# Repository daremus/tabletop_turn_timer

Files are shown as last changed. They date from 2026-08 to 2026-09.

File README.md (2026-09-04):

This is a single duration turn timer for tabletop games. It's like an hourglass without the slow reset.

Attribution:
* Code: 99% Gemini.
* Everything else: 99% me.

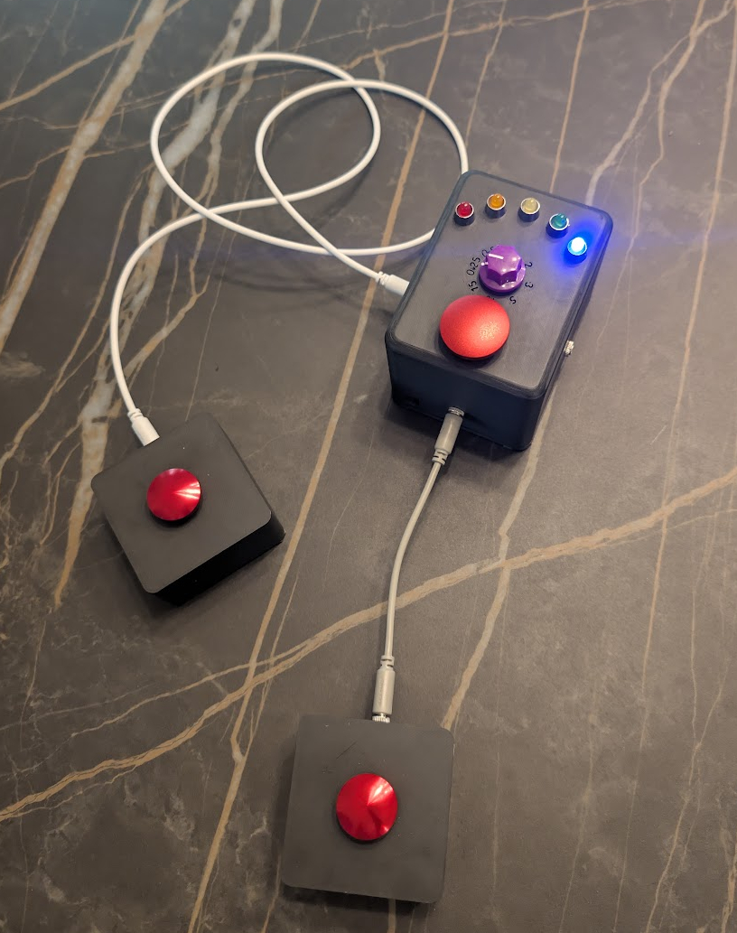
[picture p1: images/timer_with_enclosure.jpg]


## Basic Usage

Everyone has the same time for each turn. The timer resets to that time after every turn.

1. Use the knob to Select a turn duration (t).
1. Turn on timer
1. Press a button: starts a timer
1. Player presses the button when their turn is complete, timer starts the next player's turn.
1. If the timer ends before a button is pressed, the device will beep and then sleep.
1. Double press the button to put the timer to sleep.
1. If the timer is sleeping, press the button to start the next turn
1. LEDs indicate the remaining duration in t/6 chunks. LED 1 lights for the first 1/6 of a turn, LED 2 lights for the second 1/6, and so on. LED 5 lights for the fifth chunk and then flashes for the final chunk.

## Details
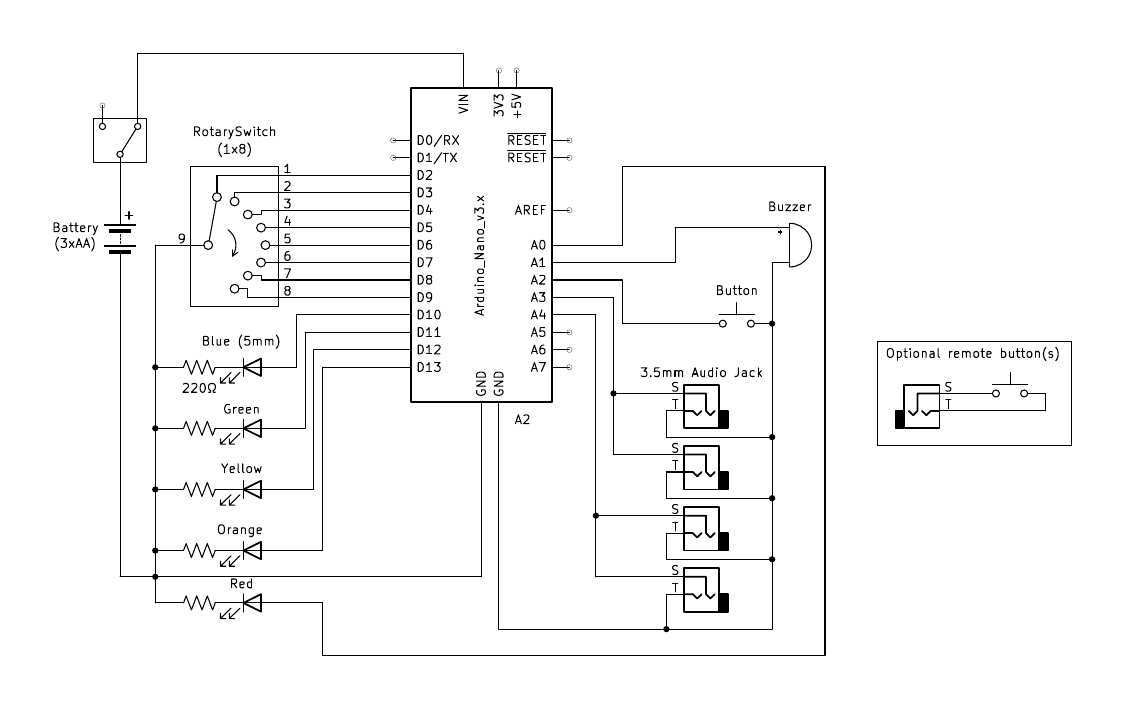
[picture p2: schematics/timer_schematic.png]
* Wiring schematic: 
* TS jacks are used to hook up external buttons and are not really needed.
  
## Components
* Panel mount mushroom head buttons: [22mm](https://www.amazon.com/dp/B0CKV6B81P), [16mm (1)](https://www.sparkfun.com/16mm-metal-push-button-switch-mushroom-head-red.html), [16mm (2)](https://www.amazon.com/dp/B0FM3VK8YW)
* [Arduino Nano clone](https://www.amazon.com/dp/B0F6Y7GS4Q) / [Arduino Nano Every](https://www.sparkfun.com/arduino-nano-every.html)
* [3.5mm mono jacks](https://www.amazon.com/dp/B0CF9DQYQ6)
* [mini speaker](https://www.amazon.com/dp/B0D7SC3ZFG)/[Buzzer](https://www.amazon.com/dp/B07VK1GJ9X)
* [Battery holder](https://www.sparkfun.com/battery-holder-3xaa-with-cover-and-switch-bare-wire.html) - switch removed and replaced with something like [this one](https://www.sparkfun.com/mini-power-switch-spdt.html) glued to the enclosure.
* [LED holders](https://www.sparkfun.com/led-holder-5mm-chrome-finish.html)
* M2 x 4mm [heat set threaded inserts](https://www.amazon.com/dp/B0FD7DQS8Y)
* M2 x 5mm screws
* [Solderable breadboard](https://www.amazon.com/dp/B0B27XB69M)

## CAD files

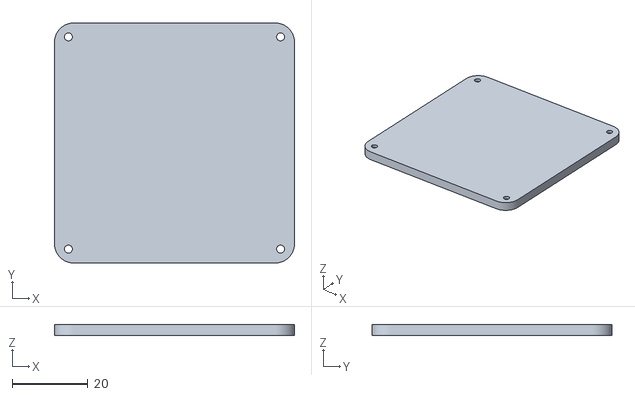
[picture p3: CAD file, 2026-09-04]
enclosures/remote button enclosure bottom.stl
63.5 x 63.5 x 3.00

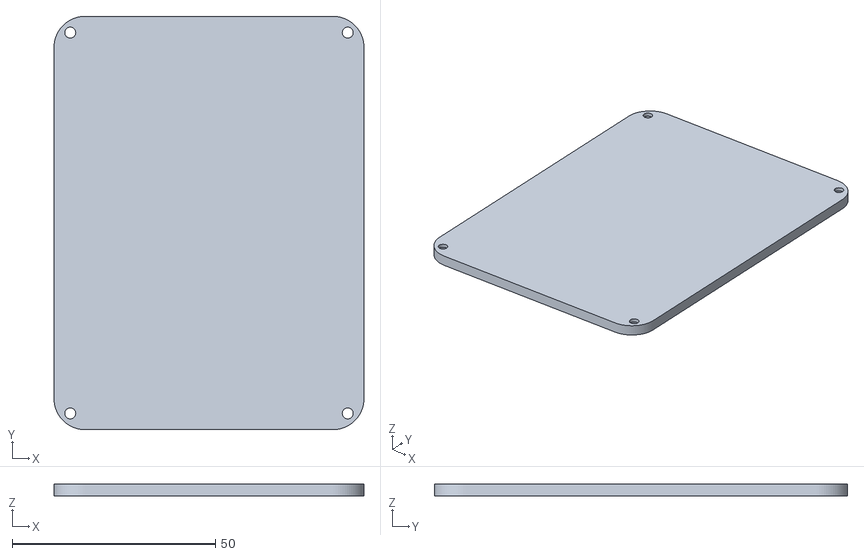
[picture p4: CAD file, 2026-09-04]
enclosures/enclosure bottom.stl
76.2 x 101.6 x 3.00

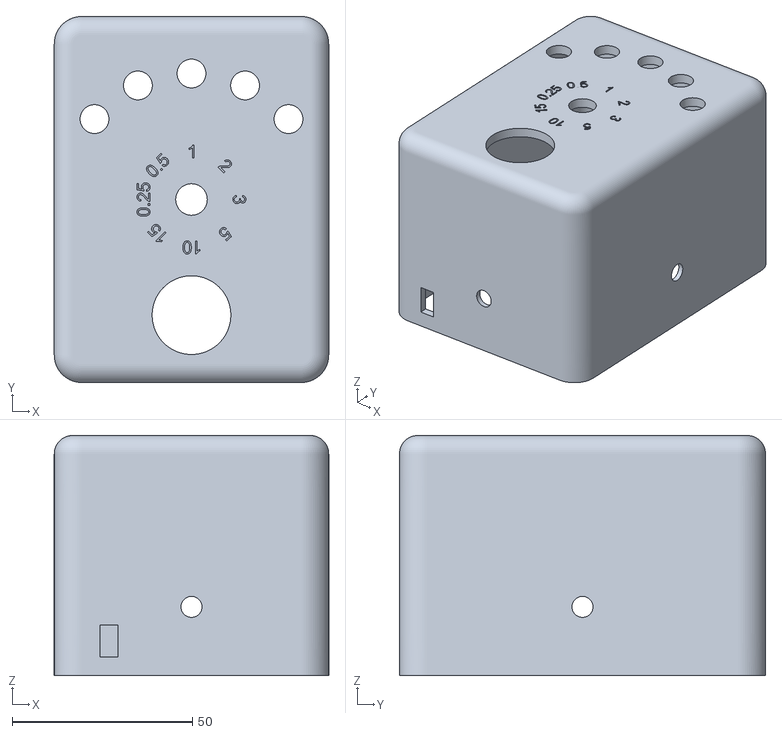
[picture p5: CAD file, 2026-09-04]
enclosures/enclosure.stl
76.2 x 101.6 x 66.6

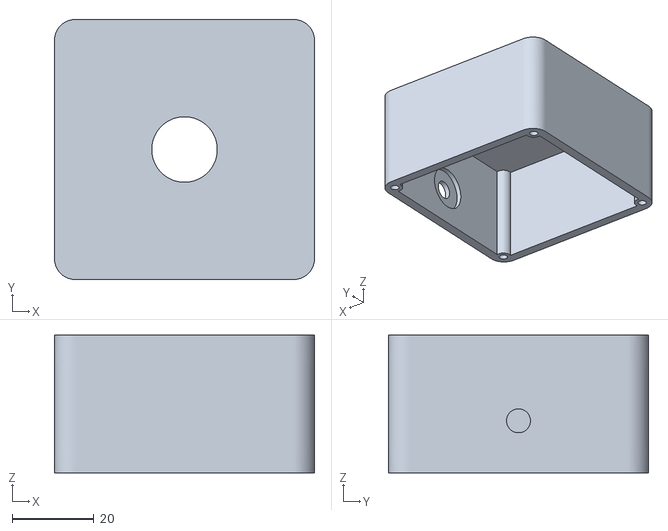
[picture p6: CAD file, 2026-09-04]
enclosures/remote button enclosure.stl
63.5 x 63.5 x 33.6

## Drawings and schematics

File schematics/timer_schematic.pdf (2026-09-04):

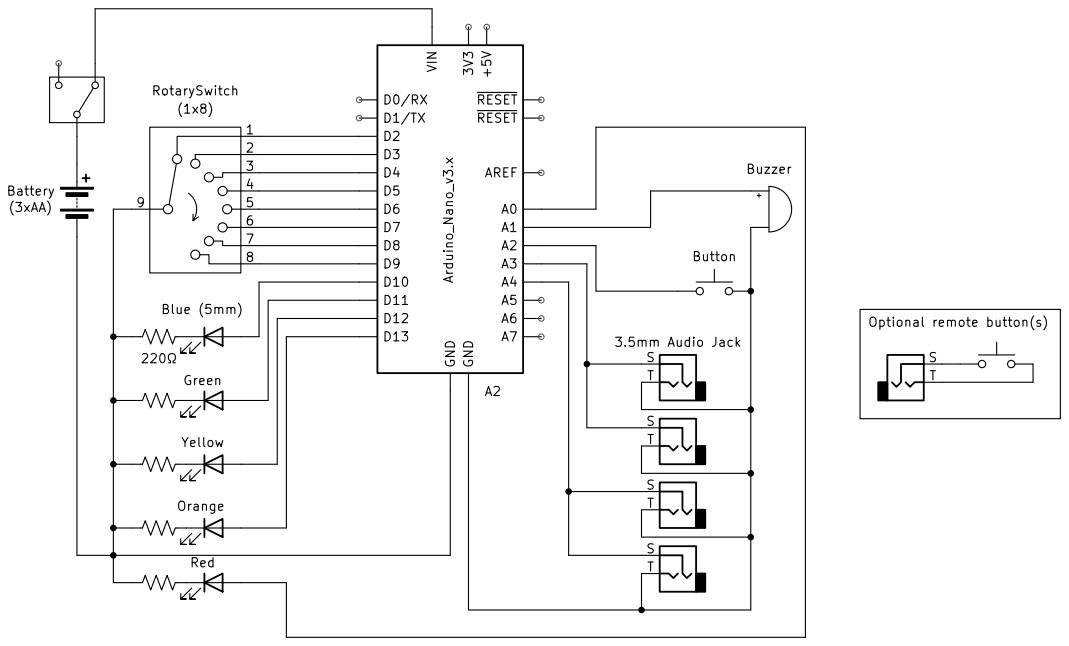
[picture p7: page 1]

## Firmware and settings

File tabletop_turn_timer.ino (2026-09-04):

/*
  Tabletop Game Timer
  
  Turn-based countdown timer configured with an 8-position rotary switch,
  remote player jacks, main button, passive piezo sounder (B0D7SC3ZFG),
  and a 5-LED display.
*/

// ==========================================
// PIN DEFINITIONS
// ==========================================
const uint8_t rotaryPins[] = {2, 3, 4, 5, 6, 7, 8, 9};
const uint8_t numRotaryPositions = sizeof(rotaryPins) / sizeof(rotaryPins[0]);

const uint8_t jackPins[] = {A3, A4};
const uint8_t numJacks = sizeof(jackPins) / sizeof(jackPins[0]);

const uint8_t mainButtonPin = A2;
const uint8_t buzzerPin = A1; // Passive Piezo Sounder (B0D7SC3ZFG)

// LED Pins: LED1 = D10 (PWM), LED2 = D11 (PWM), LED3 = D12, LED4 = D13, LED5 = A0
const uint8_t ledPins[] = {10, 11, 12, 13, A0};
const uint8_t numLeds = sizeof(ledPins) / sizeof(ledPins[0]);

// ==========================================
// CONFIGURATION & PRESETS
// ==========================================
// Durations for Positions 1 to 8: 1m, 2m, 3m, 5m, 10m, 15m, 15s, 30s
const uint32_t durationPresetsMs[] = {
  60000UL, 120000UL, 180000UL, 300000UL,
  600000UL, 900000UL, 15000UL, 30000UL
};

// Input debouncing & multi-tap detection
const uint32_t debounceDelayMs = 35;
const uint32_t doubleTapWindowMs = 380;

// Alarm sequence: 3 beeps driven at the piezo's resonant frequency (3.1 kHz)
const uint8_t maxAlarmBeeps = 3;
const uint32_t alarmBeepDurationMs = 200;
const uint16_t alarmResonantFreqHz = 3100;

// Turn-start sweep: 2 runs (LED1 -> LED5 -> LED1, 9 steps over ~0.5s)
const uint8_t startSweepPattern[] = {0, 1, 2, 3, 4, 3, 2, 1, 0};
const uint8_t numSweepSteps = sizeof(startSweepPattern);
const uint32_t sweepStepIntervalMs = 55; // 9 * 55ms = 495ms

// Turn-start tone: Warm ~450 Hz "boooop" (1111 µs half-period) over 120 ms
const uint32_t startToneDurationMs = 120;
const uint32_t toneToggleHalfPeriodUs = 1111;

// Sleep animation (center-out sweep + hardware PWM breathing)
const uint32_t sleepOutwardStepMs = 140;
const uint32_t pulseUpdateIntervalMs = 20;

// ==========================================
// STATE MACHINE & RUNTIME VARIABLES
// ==========================================
enum TimerState {
  STATE_IDLE,
  STATE_RUNNING,
  STATE_ALARM,
  STATE_START_ALERT,
  STATE_SLEEP_SWEEP,
  STATE_SLEEPING
};

TimerState currentState = STATE_IDLE;

// Timing counters
uint32_t totalDurationMs = 60000UL;
uint32_t timeRemainingMs = 60000UL;
uint32_t lastTimerUpdateMs = 0;

// Alarm tracking
uint32_t lastAlarmToggleMs = 0;
uint8_t alarmBeepCount = 0;
bool alarmBeepActive = false;

// Turn-start animation tracking
uint32_t startAlertBeginMs = 0;
uint32_t lastSweepStepMs = 0;
uint32_t lastToneToggleUs = 0;
uint8_t currentSweepIndex = 0;
bool tonePinState = false;

// Sleep sequence tracking
uint32_t lastSleepSweepMs = 0;
uint32_t lastPulseUpdateMs = 0;
uint8_t sleepSweepStep = 0;
int16_t pulseBrightness = 0;
int8_t pulseDirection = 4;

// Button debounce tracking
bool lastRawMainBtn = HIGH;
bool stableMainBtn = HIGH;
uint32_t lastMainDebounceMs = 0;

bool lastRawJack[numJacks] = {HIGH, HIGH};
bool stableJack[numJacks] = {HIGH, HIGH};
uint32_t lastJackDebounceMs[numJacks] = {0, 0};

uint8_t clickCount = 0;
uint32_t lastClickTimeMs = 0;

// ==========================================
// FUNCTION DECLARATIONS
// ==========================================
void handleInputs();
void updateTimer();
void updateStartAlert();
void updateSleepAnimation();
void updateRunningLeds();
void updateAlarm();
void setAllLeds(uint8_t state);
void resetPwmPins();
void silenceBuzzer();
uint32_t readSelectedDuration();
void triggerTurnStart();
void triggerSleepSequence();

// ==========================================
// SETUP & MAIN LOOP
// ==========================================
void setup() {
  for (uint8_t i = 0; i < numRotaryPositions; i++) {
    pinMode(rotaryPins[i], INPUT_PULLUP);
  }

  for (uint8_t i = 0; i < numJacks; i++) {
    pinMode(jackPins[i], INPUT_PULLUP);
  }

  pinMode(mainButtonPin, INPUT_PULLUP);
  pinMode(buzzerPin, OUTPUT);
  silenceBuzzer();

  for (uint8_t i = 0; i < numLeds; i++) {
    pinMode(ledPins[i], OUTPUT);
    digitalWrite(ledPins[i], LOW);
  }

  totalDurationMs = readSelectedDuration();
  timeRemainingMs = totalDurationMs;
}

void loop() {
  handleInputs();
  updateTimer();
  updateStartAlert();
  updateSleepAnimation();
  updateRunningLeds();
  updateAlarm();
}

// ==========================================
// HELPER UTILITIES
// ==========================================
void setAllLeds(uint8_t state) {
  for (uint8_t i = 0; i < numLeds; i++) {
    digitalWrite(ledPins[i], state);
  }
}

void resetPwmPins() {
  analogWrite(ledPins[0], 0);
  analogWrite(ledPins[1], 0);
}

void silenceBuzzer() {
  noTone(buzzerPin);
  digitalWrite(buzzerPin, LOW);
  tonePinState = false;
}

uint32_t readSelectedDuration() {
  for (uint8_t i = 0; i < numRotaryPositions; i++) {
    if (digitalRead(rotaryPins[i]) == LOW) {
      return durationPresetsMs[i];
    }
  }
  return durationPresetsMs[0];
}

// ==========================================
// STATE TRIGGERS
// ==========================================
void triggerTurnStart() {
  startAlertBeginMs = millis();
  lastSweepStepMs = startAlertBeginMs;
  lastToneToggleUs = micros();
  currentSweepIndex = 0;

  resetPwmPins();
  setAllLeds(LOW);
  digitalWrite(ledPins[startSweepPattern[0]], HIGH);

  currentState = STATE_START_ALERT;
}

void triggerSleepSequence() {
  silenceBuzzer();
  resetPwmPins();
  setAllLeds(LOW);

  sleepSweepStep = 0;
  lastSleepSweepMs = millis();
  currentState = STATE_SLEEP_SWEEP;
}

// ==========================================
// INPUT HANDLING & DEBOUNCE
// ==========================================
void handleInputs() {
  const uint32_t now = millis();
  bool pressDetected = false;

  // 1. Debounce Main Pushbutton
  bool rawMain = digitalRead(mainButtonPin);
  if (rawMain != lastRawMainBtn) {
    lastMainDebounceMs = now;
  }
  lastRawMainBtn = rawMain;

  if ((now - lastMainDebounceMs) > debounceDelayMs) {
    if (rawMain != stableMainBtn) {
      stableMainBtn = rawMain;
      if (stableMainBtn == LOW) {
        pressDetected = true;
      }
    }
  }

  // 2. Debounce External Player Jacks
  for (uint8_t i = 0; i < numJacks; i++) {
    bool rawJack = digitalRead(jackPins[i]);
    if (rawJack != lastRawJack[i]) {
      lastJackDebounceMs[i] = now;
    }
    lastRawJack[i] = rawJack;

    if ((now - lastJackDebounceMs[i]) > debounceDelayMs) {
      if (rawJack != stableJack[i]) {
        stableJack[i] = rawJack;
        if (stableJack[i] == LOW) {
          pressDetected = true;
        }
      }
    }
  }

  // 3. Multi-tap Resolution
  if (pressDetected) {
    clickCount++;
    lastClickTimeMs = now;

    if (clickCount >= 2) {
      clickCount = 0;
      triggerSleepSequence();
    }
  }

  if (clickCount == 1 && (now - lastClickTimeMs > doubleTapWindowMs)) {
    clickCount = 0;
    triggerTurnStart();
  }
}

// ==========================================
// ALERT, SLEEP, AND ALARM LOGIC
// ==========================================
void updateStartAlert() {
  if (currentState != STATE_START_ALERT) {
    return;
  }

  const uint32_t nowMs = millis();
  const uint32_t toneElapsedMs = nowMs - startAlertBeginMs;

  // Clean ~450 Hz "boooop" on passive piezo with soft envelope
  if (toneElapsedMs < startToneDurationMs) {
    const uint32_t nowUs = micros();
    if (nowUs - lastToneToggleUs >= toneToggleHalfPeriodUs) {
      lastToneToggleUs = nowUs;
      tonePinState = !tonePinState;

      bool allowPulse = true;
      if (toneElapsedMs < 20) {
        // Soft attack ramp
        allowPulse = (toneElapsedMs % 8 < 4);
      } else if (toneElapsedMs > (startToneDurationMs - 25)) {
        // Soft decay tail
        allowPulse = (toneElapsedMs % 8 < 3);
      }

      digitalWrite(buzzerPin, (tonePinState && allowPulse) ? HIGH : LOW);
    }
  } else {
    silenceBuzzer();
  }

  // 2-run sweep animation (LED1 -> LED5 -> LED1)
  if (nowMs - lastSweepStepMs >= sweepStepIntervalMs) {
    lastSweepStepMs = nowMs;
    currentSweepIndex++;

    if (currentSweepIndex >= numSweepSteps) {
      silenceBuzzer();
      setAllLeds(LOW);

      totalDurationMs = readSelectedDuration();
      timeRemainingMs = totalDurationMs;
      lastTimerUpdateMs = millis();
      currentState = STATE_RUNNING;
      return;
    }

    const uint8_t activeLed = startSweepPattern[currentSweepIndex];
    for (uint8_t i = 0; i < numLeds; i++) {
      digitalWrite(ledPins[i], (i == activeLed) ? HIGH : LOW);
    }
  }
}

void updateSleepAnimation() {
  const uint32_t nowMs = millis();

  // Phase 1: Center-out sweep
  if (currentState == STATE_SLEEP_SWEEP) {
    if (nowMs - lastSleepSweepMs >= sleepOutwardStepMs) {
      lastSleepSweepMs = nowMs;
      sleepSweepStep++;

      setAllLeds(LOW);

      if (sleepSweepStep == 1) {
        digitalWrite(ledPins[2], HIGH); // Center LED3
      } else if (sleepSweepStep == 2) {
        digitalWrite(ledPins[1], HIGH); // LED2 & LED4
        digitalWrite(ledPins[3], HIGH);
      } else if (sleepSweepStep == 3) {
        digitalWrite(ledPins[0], HIGH); // LED1 & LED5
        digitalWrite(ledPins[4], HIGH);
      } else {
        pulseBrightness = 0;
        pulseDirection = 4;
        currentState = STATE_SLEEPING;
      }
    }
    return;
  }

  // Phase 2: Hardware PWM breathing on LED1 (D10) and LED2 (D11) in antiphase
  if (currentState == STATE_SLEEPING) {
    if (nowMs - lastPulseUpdateMs >= pulseUpdateIntervalMs) {
      lastPulseUpdateMs = nowMs;

      pulseBrightness += pulseDirection;
      if (pulseBrightness >= 255) {
        pulseBrightness = 255;
        pulseDirection = -pulseDirection;
      } else if (pulseBrightness <= 0) {
        pulseBrightness = 0;
        pulseDirection = -pulseDirection;
      }

      analogWrite(ledPins[0], pulseBrightness);
      analogWrite(ledPins[1], 255 - pulseBrightness);
    }
  }
}

void updateTimer() {
  if (currentState != STATE_RUNNING) {
    return;
  }

  const uint32_t nowMs = millis();
  const uint32_t elapsedMs = nowMs - lastTimerUpdateMs;
  lastTimerUpdateMs = nowMs;

  if (elapsedMs >= timeRemainingMs) {
    timeRemainingMs = 0;
    currentState = STATE_ALARM;
    alarmBeepCount = 0;
    alarmBeepActive = false;
    lastAlarmToggleMs = nowMs;
  } else {
    timeRemainingMs -= elapsedMs;
  }
}

void updateRunningLeds() {
  if (currentState != STATE_RUNNING) {
    if (currentState == STATE_IDLE || currentState == STATE_ALARM) {
      setAllLeds(LOW);
    }
    return;
  }

  const uint32_t elapsedMs = totalDurationMs - timeRemainingMs;
  const uint32_t stageDurationMs = totalDurationMs / numLeds;
  uint8_t activeStage = elapsedMs / stageDurationMs;

  if (activeStage >= numLeds) {
    activeStage = numLeds - 1;
  }

  setAllLeds(LOW);

  // During the final half of the last segment (last 10%), blink LED5
  const uint32_t finalThresholdMs = totalDurationMs - (stageDurationMs / 2);
  if (elapsedMs >= finalThresholdMs) {
    bool blink = (millis() / 250) % 2 == 0;
    digitalWrite(ledPins[4], blink ? HIGH : LOW);
  } else {
    digitalWrite(ledPins[activeStage], HIGH);
  }
}

void updateAlarm() {
  if (currentState != STATE_ALARM) {
    return;
  }

  if (alarmBeepCount >= maxAlarmBeeps) {
    silenceBuzzer();
    return;
  }

  const uint32_t nowMs = millis();
  if (nowMs - lastAlarmToggleMs >= alarmBeepDurationMs) {
    lastAlarmToggleMs = nowMs;
    alarmBeepActive = !alarmBeepActive;

    if (alarmBeepActive) {
      // Passive piezo sounder driven at resonant peak for maximum volume
      tone(buzzerPin, alarmResonantFreqHz);
    } else {
      noTone(buzzerPin);
      digitalWrite(buzzerPin, LOW);
      alarmBeepCount++;
    }
  }
}

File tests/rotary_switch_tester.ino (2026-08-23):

// ==========================================
// PIN DEFINITIONS
// ==========================================

// Rotary Switch Positions 1 through 8
const int ROTARY_PINS[] = {2, 3, 4, 5, 6, 7, 8, 9};
const int NUM_ROTARY_POSITIONS = 8;

// Durations matching positions 1 to 8:
// 1m, 2m, 3m, 5m, 10m, 15m, 15s, 30s
const unsigned long DURATION_PRESETS_MS[] = {
  60000UL,   // Pos 1: 1 min
  120000UL,  // Pos 2: 2 min
  180000UL,  // Pos 3: 3 min
  300000UL,  // Pos 4: 5 min
  600000UL,  // Pos 5: 10 min
  900000UL,  // Pos 6: 15 min
  15000UL,   // Pos 7: 15 sec
  30000UL    // Pos 8: 30 sec
};

// 4 Remote Player Audio Jacks (J1, J2, J3, J4)
const int JACK_PINS[] = {10, 11, 12, 13};
const int NUM_JACKS = 4;

// Main Enclosure Pushbutton (SW2)
const int MAIN_BUTTON_PIN = A1;

// Piezo Buzzer (BZ1)
const int BUZZER_PIN = A0;

// 5 LEDs (LED1 to LED5)
const int LED_PINS[] = {A3, A4, A5, A6, A7};
const int NUM_LEDS = 5;

// ==========================================
// STATE MACHINE & TIMING VARIABLES
// ==========================================
enum TimerState { IDLE, RUNNING, PAUSED, ALARM };
TimerState currentState = IDLE;

unsigned long totalTimerDurationMs = 60000UL;
unsigned long timeRemainingMs = 60000UL;
unsigned long lastUpdateMillis = 0;
unsigned long lastBeepMillis = 0;

// Diagnostic Tracker for Rotary Serial Output
int lastReportedPos = -1;

// Alarm Beeper Logic (3 Tones)
int beepCount = 0;
bool beepActive = false;
const int MAX_BEEPS = 3;
const unsigned long BEEP_DURATION_MS = 200;

// Button Debouncing & Double-Tap Logic (Main Button SW2)
const unsigned long DEBOUNCE_DELAY = 50;
const unsigned long DOUBLE_TAP_GAP = 300;

bool lastRawMainBtn = HIGH;
bool stableMainBtn = HIGH;
unsigned long lastDebounceMain = 0;
unsigned long lastReleaseTime = 0;
int tapCount = 0;

// Remote Audio Jack Debounce States
bool lastJackState[NUM_JACKS] = {HIGH, HIGH, HIGH, HIGH};
bool stableJackState[NUM_JACKS] = {HIGH, HIGH, HIGH, HIGH};
unsigned long lastJackDebounce[NUM_JACKS] = {0, 0, 0, 0};

// ==========================================
// SETUP
// ==========================================
void setup() {
  Serial.begin(9600);

  // Initialize Rotary Switch Pins
  for (int i = 0; i < NUM_ROTARY_POSITIONS; i++) {
    pinMode(ROTARY_PINS[i], INPUT_PULLUP);
  }

  // Initialize Remote Player Audio Jacks
  for (int i = 0; i < NUM_JACKS; i++) {
    pinMode(JACK_PINS[i], INPUT_PULLUP);
  }

  // Initialize Main Button, Buzzer, and LEDs
  pinMode(MAIN_BUTTON_PIN, INPUT_PULLUP);
  pinMode(BUZZER_PIN, OUTPUT);
  for (int i = 0; i < NUM_LEDS; i++) {
    pinMode(LED_PINS[i], OUTPUT);
  }

  // Read initial duration from rotary switch
  totalTimerDurationMs = readSelectedDuration();
  timeRemainingMs = totalTimerDurationMs;
  updateLEDs();
}

// ==========================================
// MAIN LOOP
// ==========================================
void loop() {
  checkRotarySwitchPosition();
  handleMainButton();
  handlePlayerJacks();
  updateTimer();
  updateLEDs();
  updateAlarm();
}

// ==========================================
// ROTARY SWITCH HELPERS
// ==========================================
void checkRotarySwitchPosition() {
  int currentPos = -1;
  int activePin = -1;

  for (int i = 0; i < NUM_ROTARY_POSITIONS; i++) {
    if (digitalRead(ROTARY_PINS[i]) == LOW) {
      currentPos = i + 1; // 1 to 8
      activePin = ROTARY_PINS[i];
      break;
    }
  }

  if (currentPos != lastReportedPos) {
    lastReportedPos = currentPos;
    if (currentPos != -1) {
      Serial.print("Rotary Switch Position: ");
      Serial.print(currentPos);
      Serial.print(" | Arduino Pin: D");
      Serial.print(activePin);
      Serial.print(" | Duration: ");
      Serial.print(DURATION_PRESETS_MS[currentPos - 1] / 1000);
      Serial.println("s");
    } else {
      Serial.println("Switch is between notches or not grounded (All pins HIGH).");
    }
  }
}

unsigned long readSelectedDuration() {
  for (int i = 0; i < NUM_ROTARY_POSITIONS; i++) {
    if (digitalRead(ROTARY_PINS[i]) == LOW) {
      return DURATION_PRESETS_MS[i];
    }
  }
  return DURATION_PRESETS_MS[0]; // Default to Pos 1 (1 min) if between notches
}

// ==========================================
// TIMER START / RESET / PAUSE LOGIC
// ==========================================
void startOrResetTimer() {
  noTone(BUZZER_PIN);
  totalTimerDurationMs = readSelectedDuration(); // Update to current rotary setting
  timeRemainingMs = totalTimerDurationMs;
  lastUpdateMillis = millis();
  currentState = RUNNING;
}

void togglePause() {
  if (currentState == RUNNING) {
    currentState = PAUSED;
  } else if (currentState == PAUSED) {
    lastUpdateMillis = millis();
    currentState = RUNNING;
  }
}

// ==========================================
// INPUT HANDLERS
// ==========================================
void handleMainButton() {
  bool reading = digitalRead(MAIN_BUTTON_PIN);

  if (reading != lastRawMainBtn) {
    lastDebounceMain = millis();
  }
  lastRawMainBtn = reading;

  if ((millis() - lastDebounceMain) > DEBOUNCE_DELAY) {
    if (reading != stableMainBtn) {
      stableMainBtn = reading;

      // Active LOW press
      if (stableMainBtn == LOW) {
        tapCount++;
        if (tapCount == 1) {
          lastReleaseTime = millis();
        }
      }
    }
  }

  // Handle single vs double tap
  if (tapCount > 0) {
    if (tapCount == 2) {
      togglePause();
      tapCount = 0;
    } else if (millis() - lastReleaseTime > DOUBLE_TAP_GAP) {
      startOrResetTimer();
      tapCount = 0;
    }
  }
}

void handlePlayerJacks() {
  for (int i = 0; i < NUM_JACKS; i++) {
    bool reading = digitalRead(JACK_PINS[i]);

    if (reading != lastJackState[i]) {
      lastJackDebounce[i] = millis();
    }
    lastJackState[i] = reading;

    if ((millis() - lastJackDebounce[i]) > DEBOUNCE_DELAY) {
      if (reading != stableJackState[i]) {
        stableJackState[i] = reading;

        // Player pressed end-of-turn button
        if (stableJackState[i] == LOW) {
          startOrResetTimer();
        }
      }
    }
  }
}

// ==========================================
// TIMER COUNTDOWN LOGIC
// ==========================================
void updateTimer() {
  if (currentState != RUNNING) return;

  unsigned long currentMillis = millis();
  unsigned long elapsed = currentMillis - lastUpdateMillis;
  lastUpdateMillis = currentMillis;

  if (elapsed >= timeRemainingMs) {
    timeRemainingMs = 0;
    currentState = ALARM;
    beepCount = 0;
    beepActive = false;
    lastBeepMillis = currentMillis;
  } else {
    timeRemainingMs -= elapsed;
  }
}
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

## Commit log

2026-08-18 Add README for tabletop timer project
    Added a detailed description of the tabletop timer, including usage instructions and initial logic for LED indicators.
2026-08-18 Update README with links to schematic and enclosure
2026-08-18 Update image links in README for schematic and enclosure
2026-08-18 Refactor timer logic table formatting in README
    Removed spaces around multiplication operators in the timer logic table for consistency.
2026-08-18 Add tabletop_turn_timer functionality
    Implement tabletop turn timer with rotary switch, audio jacks, and LED indicators.
2026-08-18 Revise README description and image placement
    Updated the description of the timer and added an image.
2026-08-23 Fix link formatting for Arduino Nano Every
2026-08-23 Add rotary switch debug functionality
2026-09-01 update pin map
2026-09-04 File organization and update of accessory files.
    [tabletop_game_timer_v1.kicad_sch]
2026-09-04 Polishing. Swapped buzzer for a mini speaker, improved tones, lighting logic.
    [tabletop_turn_timer.ino]
2026-09-04 added enclosure .stl files.
    [enclosure bottom.stl, enclosure.stl, remote button enclosure bottom.stl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]
